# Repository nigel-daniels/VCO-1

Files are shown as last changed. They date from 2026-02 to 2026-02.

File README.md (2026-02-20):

# VCO 1

Here is my first VCO based on the work of Moritz Klein and his great series of VCO videos found [here](https://www.youtube.com/watch?v=QBatvo8bCa4&list=PLHeL0JWdJLvTuGCyC3qvx0RM39YvopVQN). I based the schematic on his work and the Erica Synths kit schematic but I added in the sawtooth-to-triangle wave converter. 

The PCB design is my own and I designed it as a two layer pcb made of two double sided pcbs. I ended up self-etching, hence the registration pin-holes next to the drill holes for the standoffs on the pcb designs.

I hope you find this useful, and a huge thanks to Moritz Klein for getting me started down this path!

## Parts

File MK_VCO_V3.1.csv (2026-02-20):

Reference | Qty | Value | DNP | Exclude from BOM | Exclude from Board | Footprint | Datasheet
C1 | 1 | 2.2nF |  |  |  | Capacitor_THT:C_Disc_D4.7mm_W2.5mm_P5.00mm | ~
C2,C3,C4 | 3 | 1μF |  |  |  | Capacitor_THT:C_Disc_D4.7mm_W2.5mm_P5.00mm | ~
C13,C14,C15,C16,C17,C20,C21 | 7 | 0.1μF |  |  |  | Capacitor_THT:C_Disc_D4.7mm_W2.5mm_P5.00mm | ~
C18,C19 | 2 | 47μF |  |  |  | Capacitor_THT:CP_Radial_D5.0mm_P2.50mm | ~
CRS1,FIN1,PW1 | 3 | 100K |  |  |  | Potentiometer_THT:Potentiometer_Alps_RK09L_Single_Vertical | ~
D1 | 1 | 1N4148 |  |  |  | Diode_THT:D_DO-35_SOD27_P2.54mm_Vertical_KathodeUp | ~
D2,D3 | 2 | 1N4148 |  |  |  | Diode_THT:D_DO-35_SOD27_P7.62mm_Horizontal | ~
D10,D11 | 2 | 1N5819 |  |  |  | Diode_THT:D_DO-41_SOD81_P10.16mm_Horizontal | http://www.vishay.com/docs/88525/1n5817.pdf
FM1 | 1 | 1M |  |  |  | Potentiometer_THT:Potentiometer_Alps_RK09L_Single_Vertical | ~
H1,H2,H3,H4,H5,H6,H7,H8 | 8 | ~ |  | Excluded from BOM |  | MountingHole:MountingHole_2.7mm_M2.5 | ~
J1 | 1 | CV |  |  |  | Connector_Audio:Jack_3.5mm_QingPu_WQP-PJ398SM_Vertical_CircularHoles | ~
J2 | 1 | FM |  |  |  | Connector_Audio:Jack_3.5mm_QingPu_WQP-PJ398SM_Vertical_CircularHoles | ~
J3 | 1 | SAW |  |  |  | Connector_Audio:Jack_3.5mm_QingPu_WQP-PJ398SM_Vertical_CircularHoles | ~
J4 | 1 | PWM |  |  |  | Connector_Audio:Jack_3.5mm_QingPu_WQP-PJ398SM_Vertical_CircularHoles | ~
J5 | 1 | PUL |  |  |  | Connector_Audio:Jack_3.5mm_QingPu_WQP-PJ398SM_Vertical_CircularHoles | ~
J6 | 1 | TRI |  |  |  | Connector_Audio:Jack_3.5mm_QingPu_WQP-PJ398SM_Vertical_CircularHoles | ~
J7 | 1 | 1x9 f |  |  |  | Connector_PinSocket_2.54mm:PinSocket_1x09_P2.54mm_Vertical | ~
J8 | 1 | 1x9 m |  |  |  | Connector_PinHeader_2.54mm:PinHeader_1x09_P2.54mm_Vertical | ~
J9 | 1 | 1x4 f |  |  |  | Connector_PinSocket_2.54mm:PinSocket_1x04_P2.54mm_Vertical | ~
J10 | 1 | 1x4 m |  |  |  | Connector_PinHeader_2.54mm:PinHeader_1x04_P2.54mm_Vertical | ~
J11,J15 | 2 | 1x6 f |  |  |  | Connector_PinSocket_2.54mm:PinSocket_1x06_P2.54mm_Vertical | ~
J12,J16 | 2 | 1x6 m |  |  |  | Connector_PinHeader_2.54mm:PinHeader_1x06_P2.54mm_Vertical | ~
J13 | 1 | 1x2 f |  |  |  | Connector_PinSocket_2.54mm:PinSocket_1x02_P2.54mm_Vertical | ~
J14 | 1 | 1x2 m |  |  |  | Connector_PinHeader_2.54mm:PinHeader_1x02_P2.54mm_Vertical | ~
J85 | 1 | Eurorack Conn. |  |  |  | Connector_PinHeader_2.54mm:PinHeader_2x08_P2.54mm_Vertical | ~
PWM_LVL1 | 1 | 250K |  |  |  | Potentiometer_THT:Potentiometer_Alps_RK09L_Single_Vertical | ~
Q1 | 1 | BC558 |  |  |  | Package_TO_SOT_THT:TO-92_Inline_Wide | https://www.onsemi.com/pub/Collateral/BC556BTA-D.pdf
Q2 | 1 | BC548 |  |  |  | Package_TO_SOT_THT:TO-92_Inline_Wide | https://www.onsemi.com/pub/Collateral/BC550-D.pdf
R1 | 1 | 100k |  |  |  | Resistor_THT:R_Axial_DIN0204_L3.6mm_D1.6mm_P7.62mm_Horizontal | ~
R2 | 1 | 33K |  |  |  | Resistor_THT:R_Axial_DIN0204_L3.6mm_D1.6mm_P7.62mm_Horizontal | ~
R3,R4,R6,R7,R14,R17 | 6 | 100K |  |  |  | Resistor_THT:R_Axial_DIN0204_L3.6mm_D1.6mm_P7.62mm_Horizontal | ~
R5,R9 | 2 | 1M |  |  |  | Resistor_THT:R_Axial_DIN0204_L3.6mm_D1.6mm_P7.62mm_Horizontal | ~
R8 | 1 | 1K5 |  |  |  | Resistor_THT:R_Axial_DIN0204_L3.6mm_D1.6mm_P7.62mm_Horizontal | ~
R10,R11 | 2 | 100K |  |  |  | Resistor_THT:R_Axial_DIN0204_L3.6mm_D1.6mm_P2.54mm_Vertical | ~
R12 | 1 | 47K |  |  |  | Resistor_THT:R_Axial_DIN0204_L3.6mm_D1.6mm_P2.54mm_Vertical | ~
R13 | 1 | 1K |  |  |  | Resistor_THT:R_Axial_DIN0204_L3.6mm_D1.6mm_P7.62mm_Horizontal | ~
R15,R18 | 2 | 68K |  |  |  | Resistor_THT:R_Axial_DIN0204_L3.6mm_D1.6mm_P2.54mm_Vertical | ~
R16 | 1 | 14K |  |  |  | Resistor_THT:R_Axial_DIN0204_L3.6mm_D1.6mm_P7.62mm_Horizontal | ~
R19 | 1 | 1K |  |  |  | Resistor_THT:R_Axial_DIN0204_L3.6mm_D1.6mm_P2.54mm_Vertical | ~
R20 | 1 | 200K |  |  |  | Resistor_THT:R_Axial_DIN0204_L3.6mm_D1.6mm_P7.62mm_Horizontal | ~
R22 | 1 | 10K |  |  |  | Resistor_THT:R_Axial_DIN0204_L3.6mm_D1.6mm_P2.54mm_Vertical | ~
R23 | 1 | 20K |  |  |  | Resistor_THT:R_Axial_DIN0204_L3.6mm_D1.6mm_P7.62mm_Horizontal | ~
R24 | 1 | 200K |  |  |  | Resistor_THT:R_Axial_DIN0204_L3.6mm_D1.6mm_P2.54mm_Vertical | ~
R73,R74 | 2 | 10 |  |  |  | Resistor_THT:R_Axial_DIN0204_L3.6mm_D1.6mm_P7.62mm_Horizontal | ~
RV4 | 1 | 1K |  |  |  | Potentiometer_THT:Potentiometer_Bourns_3296W_Vertical | ~
RV19 | 1 | 10K |  |  |  | Potentiometer_THT:Potentiometer_Bourns_3296W_Vertical | ~
TH1,TH2,TH3,TH4 | 4 | 10K |  |  |  | Resistor_THT:R_Axial_DIN0204_L3.6mm_D1.6mm_P5.08mm_Horizontal | ~
TP1 | 1 | A1 |  |  |  | TestPoint:TestPoint_Loop_D2.50mm_Drill1.0mm | ~
TP2 | 1 | B1 |  |  |  | TestPoint:TestPoint_Loop_D2.50mm_Drill1.0mm | ~
TP3 | 1 | C1 |  |  |  | TestPoint:TestPoint_Loop_D2.50mm_Drill1.0mm | ~
TP4 | 1 | D1 |  |  |  | TestPoint:TestPoint_Loop_D2.50mm_Drill1.0mm | ~
TP13 | 1 | TO1 |  |  |  | TestPoint:TestPoint_Loop_D2.50mm_Drill1.0mm | ~
TP14 | 1 | SO1 |  |  |  | TestPoint:TestPoint_Loop_D2.50mm_Drill1.0mm | ~
TP15 | 1 | PO1 |  |  |  | TestPoint:TestPoint_Loop_D2.50mm_Drill1.0mm | ~
TP22 | 1 | Gnd |  |  |  | TestPoint:TestPoint_Loop_D2.50mm_Drill1.0mm | ~
U1 | 1 | 40106 |  |  |  | Package_DIP:DIP-14_W7.62mm | https://assets.nexperia.com/documents/data-sheet/HEF40106B.pdf
U2 | 1 | TL074 |  |  |  | Package_DIP:DIP-14_W7.62mm | http://www.ti.com/lit/ds/symlink/tl071.pdf
U3 | 1 | TL072 |  |  |  | Package_DIP:DIP-8_W7.62mm | http://www.ti.com/lit/ds/symlink/tl071.pdf

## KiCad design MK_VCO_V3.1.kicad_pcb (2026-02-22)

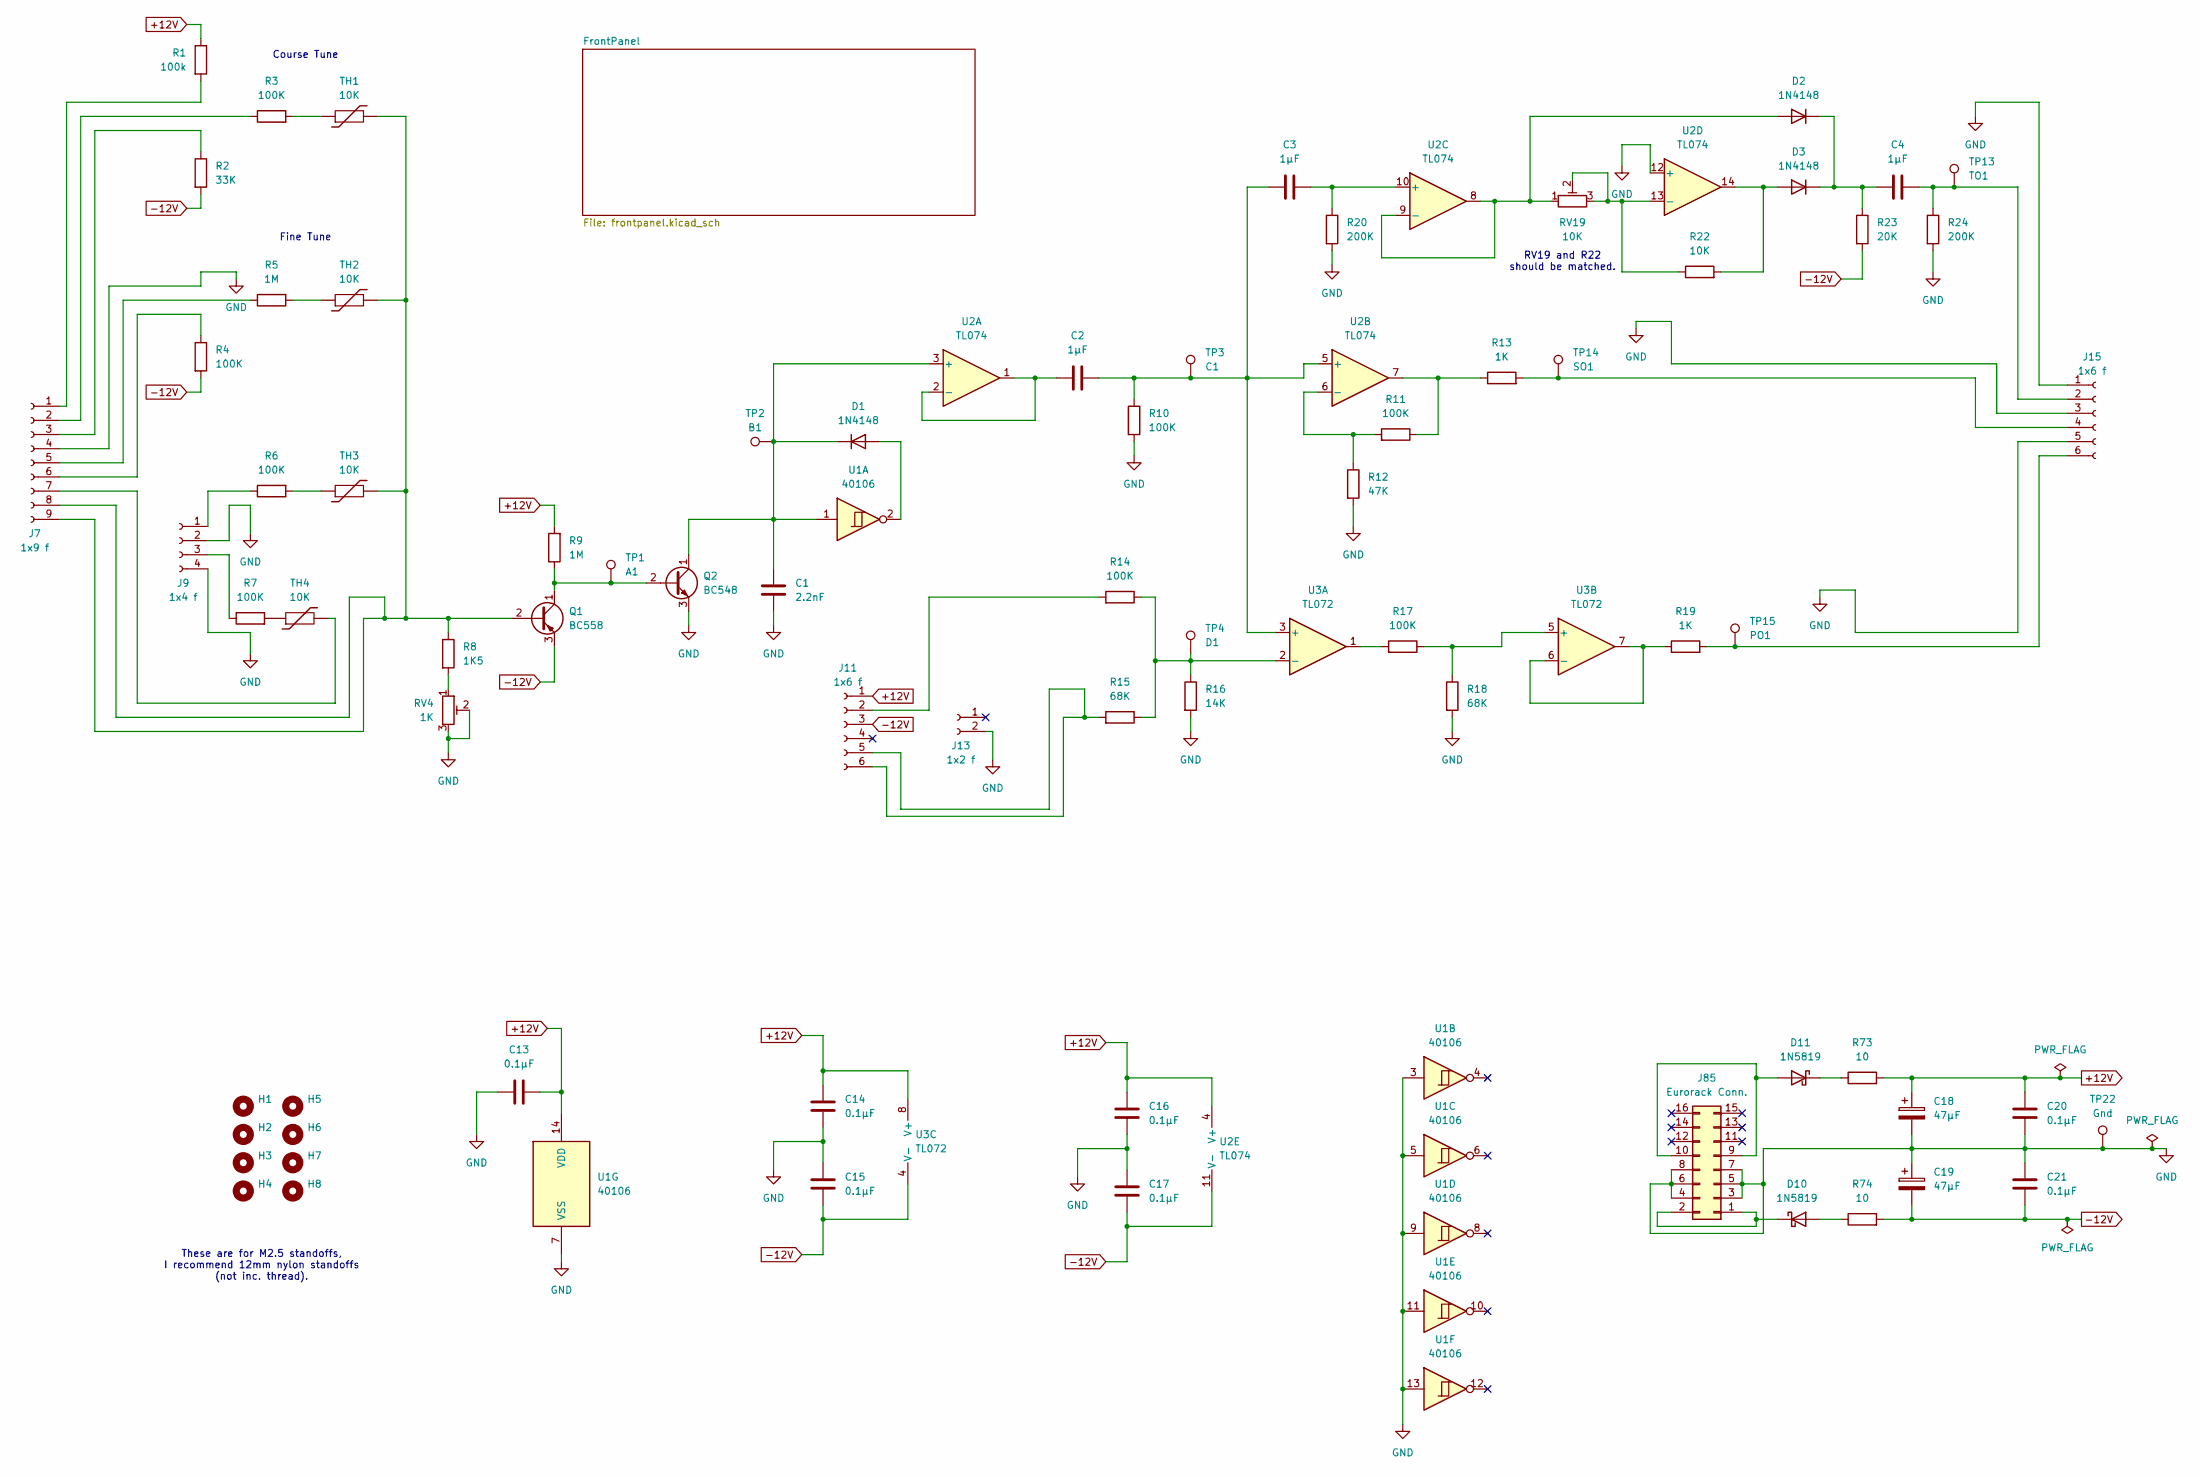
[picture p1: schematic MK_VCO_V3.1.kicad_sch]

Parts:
C1: 2.2nF; C_Disc_D4.7mm_W2.5mm_P5.00mm
C2, C3, C4: 1μF; C_Disc_D4.7mm_W2.5mm_P5.00mm
C13, C14, C15, C16, C17, C20, C21: 0.1μF; C_Disc_D4.7mm_W2.5mm_P5.00mm
C18, C19: 47μF; CP_Radial_D5.0mm_P2.50mm
D1: 1N4148; D_DO-35_SOD27_P2.54mm_Vertical_KathodeUp
D2, D3: 1N4148; D_DO-35_SOD27_P7.62mm_Horizontal
D10, D11: 1N5819; D_DO-41_SOD81_P10.16mm_Horizontal
H1, H2, H3, H4, H5, H6, H7, H8: MountingHole_2.7mm_M2.5
J7: 1x9 f; PinSocket_1x09_P2.54mm_Vertical
J9: 1x4 f; PinSocket_1x04_P2.54mm_Vertical
J11, J15: 1x6 f; PinSocket_1x06_P2.54mm_Vertical
J13: 1x2 f; PinSocket_1x02_P2.54mm_Vertical
J85: Eurorack Conn.; PinHeader_2x08_P2.54mm_Vertical
Q1: BC558; TO-92_Inline_Wide
Q2: BC548; TO-92_Inline_Wide
R1: 100k; R_Axial_DIN0204_L3.6mm_D1.6mm_P7.62mm_Horizontal
R2: 33K; R_Axial_DIN0204_L3.6mm_D1.6mm_P7.62mm_Horizontal
R3, R4, R6, R7, R14, R17: 100K; R_Axial_DIN0204_L3.6mm_D1.6mm_P7.62mm_Horizontal
R5, R9: 1M; R_Axial_DIN0204_L3.6mm_D1.6mm_P7.62mm_Horizontal
R8: 1K5; R_Axial_DIN0204_L3.6mm_D1.6mm_P7.62mm_Horizontal
R10, R11: 100K; R_Axial_DIN0204_L3.6mm_D1.6mm_P2.54mm_Vertical
R12: 47K; R_Axial_DIN0204_L3.6mm_D1.6mm_P2.54mm_Vertical
R13: 1K; R_Axial_DIN0204_L3.6mm_D1.6mm_P7.62mm_Horizontal
R15, R18: 68K; R_Axial_DIN0204_L3.6mm_D1.6mm_P2.54mm_Vertical
R16: 14K; R_Axial_DIN0204_L3.6mm_D1.6mm_P7.62mm_Horizontal
R19: 1K; R_Axial_DIN0204_L3.6mm_D1.6mm_P2.54mm_Vertical
R20: 200K; R_Axial_DIN0204_L3.6mm_D1.6mm_P7.62mm_Horizontal
R22: 10K; R_Axial_DIN0204_L3.6mm_D1.6mm_P2.54mm_Vertical
R23: 20K; R_Axial_DIN0204_L3.6mm_D1.6mm_P7.62mm_Horizontal
R24: 200K; R_Axial_DIN0204_L3.6mm_D1.6mm_P2.54mm_Vertical
R73, R74: 10; R_Axial_DIN0204_L3.6mm_D1.6mm_P7.62mm_Horizontal
RV4: 1K; Potentiometer_Bourns_3296W_Vertical
RV19: 10K; Potentiometer_Bourns_3296W_Vertical
TH1, TH2, TH3, TH4: 10K; R_Axial_DIN0204_L3.6mm_D1.6mm_P5.08mm_Horizontal
TP1: A1; TestPoint_Loop_D2.50mm_Drill1.0mm
TP2: B1; TestPoint_Loop_D2.50mm_Drill1.0mm
TP3: C1; TestPoint_Loop_D2.50mm_Drill1.0mm
TP4: D1; TestPoint_Loop_D2.50mm_Drill1.0mm
TP13: TO1; TestPoint_Loop_D2.50mm_Drill1.0mm
TP14: SO1; TestPoint_Loop_D2.50mm_Drill1.0mm
TP15: PO1; TestPoint_Loop_D2.50mm_Drill1.0mm
TP22: Gnd; TestPoint_Loop_D2.50mm_Drill1.0mm
U1: 40106; DIP-14_W7.62mm
U2: TL074; DIP-14_W7.62mm
U3: TL072; DIP-8_W7.62mm

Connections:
+12V: C13.2, C14.1, C16.1, C18.1, C20.1, J11.1, R1.1, R9.2, R73.2, U1.14 (VDD), U2.4 (V+), U3.8 (V+)
-12V: C15.2, C17.2, C19.2, C21.2, J11.3, Q1.3 (E), R2.2, R4.2, R23.2, R74.2, U2.11 (V-), U3.4 (V-)
GND: C1.2, C13.1, C14.2, C15.1, C16.2, C17.1, C18.2, C19.1, C20.2, C21.1, J7.4, J9.2, J9.4, J13.2, J15.1, J15.3, J15.5, J85.3, J85.4, J85.5, J85.6, J85.7, J85.8, Q2.3 (E), R10.2, R12.2, R16.2, R18.2, R20.2, R24.2, RV4.2, RV4.3, TP22.1, U1.3, U1.5, U1.7 (VSS), U1.9, U1.11, U1.13, U2.12 (+)
unnamed: D1.2 (A), U1.2
unnamed: C1.1, D1.1 (K), Q2.1 (C), TP2.1, U1.1, U2.3 (+)
unnamed: D2.2 (A), RV19.1, U2.8, U2.9 (-)
unnamed: C4.2, D2.1 (K), D3.1 (K), R23.1
unnamed: D3.2 (A), R22.2, U2.14
unnamed: D10.2 (A), R74.1
unnamed: D10.1 (K), J85.1, J85.2
unnamed: D11.2 (A), J85.9, J85.10
unnamed: D11.1 (K), R73.1
unnamed: J7.1, R1.2
unnamed: J7.2, R3.1
unnamed: J7.3, R2.1
unnamed: J7.5, R5.1
unnamed: J7.6, R4.1
unnamed: J7.7, TH4.2
unnamed: J7.8, J7.9, Q1.2 (B), R8.1, TH1.2, TH2.2, TH3.2
unnamed: J9.1, R6.1
unnamed: J9.3, R7.1
unnamed: J11.2, R14.2
unnamed: J11.5, J11.6, R15.2
unnamed: C4.1, J15.2, R24.1, TP13.1
unnamed: J15.4, R13.2, TP14.1
unnamed: J15.6, R19.2, TP15.1
unnamed: Q1.1 (C), Q2.2 (B), R9.1, TP1.1
unnamed: R3.2, TH1.1
unnamed: R5.2, TH2.1
unnamed: R6.2, TH3.1
unnamed: R7.2, TH4.1
unnamed: R8.2, RV4.1
unnamed: R11.1, R13.1, U2.7
unnamed: R17.2, U3.1
unnamed: C2.2, U2.1, U2.2 (-)
unnamed: C2.1, C3.2, R10.1, TP3.1, U2.5 (+), U3.3 (+)
unnamed: R11.2, R12.1, U2.6 (-)
unnamed: C3.1, R20.1, U2.10 (+)
unnamed: R22.1, RV19.2, RV19.3, U2.13 (-)
unnamed: R14.1, R15.1, R16.1, TP4.1, U3.2 (-)
unnamed: R17.1, R18.1, U3.5 (+)
unnamed: R19.1, U3.6 (-), U3.7

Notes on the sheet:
Fine Tune
Course Tune
RV19 and R22 should be matched.
These are for M2.5 standoffs, I recommend 12mm nylon standoffs (not inc. thread).

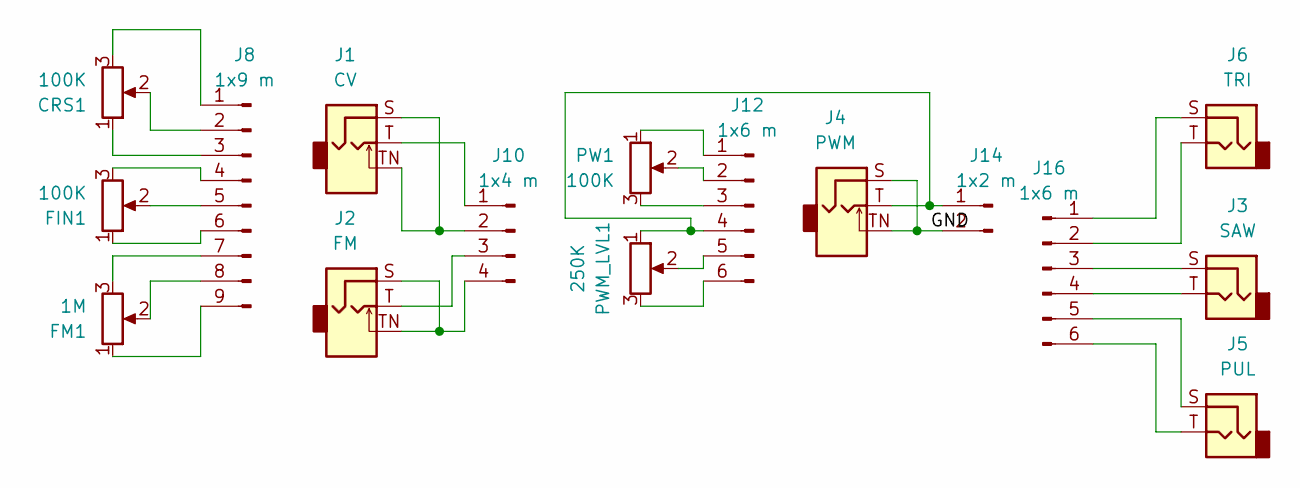
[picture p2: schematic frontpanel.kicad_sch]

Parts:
CRS1: 100K; Potentiometer_Alps_RK09L_Single_Vertical
FIN1: 100K; Potentiometer_Alps_RK09L_Single_Vertical
FM1: 1M; Potentiometer_Alps_RK09L_Single_Vertical
J1: CV; Jack_3.5mm_QingPu_WQP-PJ398SM_Vertical_CircularHoles
J2: FM; Jack_3.5mm_QingPu_WQP-PJ398SM_Vertical_CircularHoles
J3: SAW; Jack_3.5mm_QingPu_WQP-PJ398SM_Vertical_CircularHoles
J4: PWM; Jack_3.5mm_QingPu_WQP-PJ398SM_Vertical_CircularHoles
J5: PUL; Jack_3.5mm_QingPu_WQP-PJ398SM_Vertical_CircularHoles
J6: TRI; Jack_3.5mm_QingPu_WQP-PJ398SM_Vertical_CircularHoles
J8: 1x9 m; PinHeader_1x09_P2.54mm_Vertical
J10: 1x4 m; PinHeader_1x04_P2.54mm_Vertical
J12, J16: 1x6 m; PinHeader_1x06_P2.54mm_Vertical
J14: 1x2 m; PinHeader_1x02_P2.54mm_Vertical
PW1: 100K; Potentiometer_Alps_RK09L_Single_Vertical
PWM_LVL1: 250K; Potentiometer_Alps_RK09L_Single_Vertical

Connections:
/FrontPanel/GND: J4.S, J4.TN, J14.2
unnamed: CRS1.3, J8.1
unnamed: CRS1.2, J8.2
unnamed: CRS1.1, J8.3
unnamed: FIN1.3, J8.4
unnamed: FIN1.2, J8.5
unnamed: FIN1.1, J8.6
unnamed: FM1.3, J8.7
unnamed: FM1.2, J8.8
unnamed: FM1.1, J8.9
unnamed: J1.T, J10.1
unnamed: J1.S, J1.TN, J10.2
unnamed: J2.T, J10.3
unnamed: J2.S, J2.TN, J10.4
unnamed: J12.1, PW1.1
unnamed: J12.2, PW1.2
unnamed: J12.3, PW1.3
unnamed: J4.T, J12.4, J14.1, PWM_LVL1.1
unnamed: J12.5, PWM_LVL1.2
unnamed: J12.6, PWM_LVL1.3
unnamed: J6.S, J16.1
unnamed: J6.T, J16.2
unnamed: J3.S, J16.3
unnamed: J3.T, J16.4
unnamed: J5.S, J16.5
unnamed: J5.T, J16.6

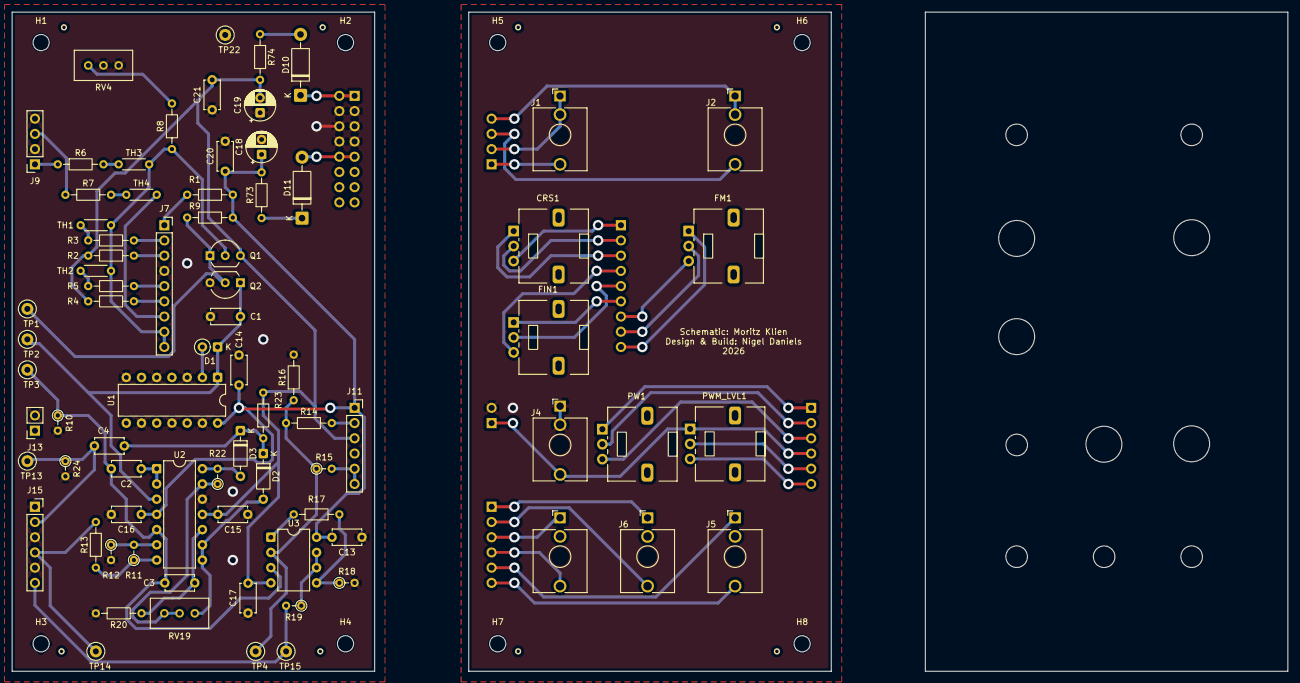
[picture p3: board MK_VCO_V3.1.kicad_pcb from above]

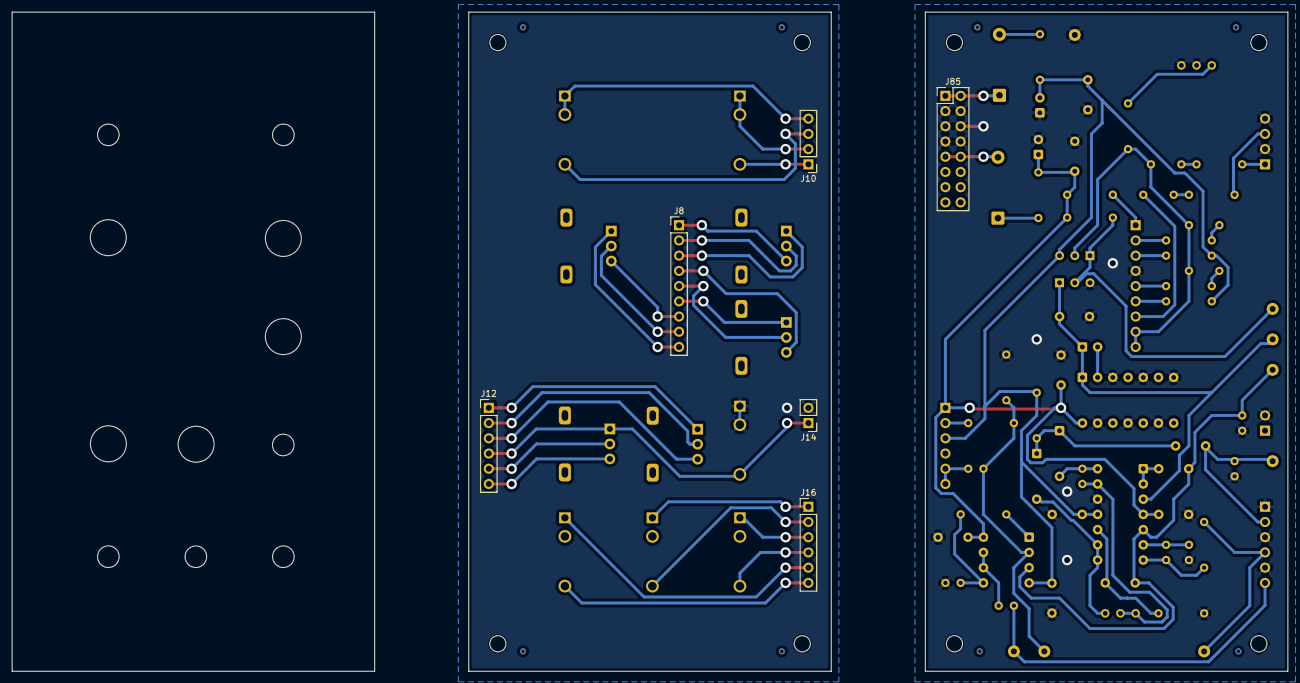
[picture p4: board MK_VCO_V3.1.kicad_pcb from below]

Board: 2 copper layers, 60.5 x 110.0 mm, 92 parts (6 on the bottom side), 68 nets.
